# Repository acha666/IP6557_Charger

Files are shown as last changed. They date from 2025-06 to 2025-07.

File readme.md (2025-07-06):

# IP6557 Charger

[Chinese Document / 中文文档](./readme-zh.md) | English Document

*A fast-charging module based on the Injoinic IP6557 buck-boost SoC*  

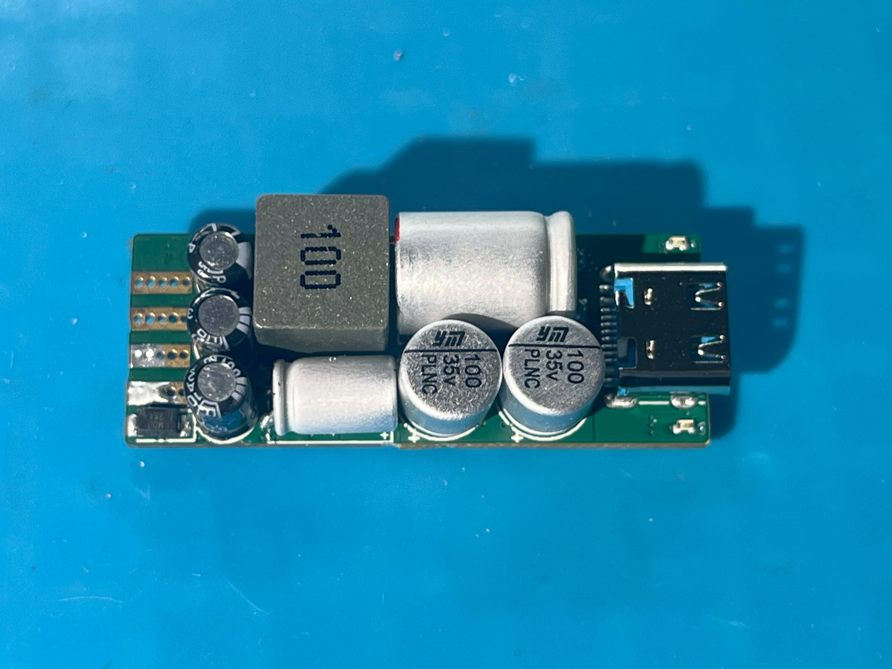
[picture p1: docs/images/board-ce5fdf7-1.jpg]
PCB Photo 1
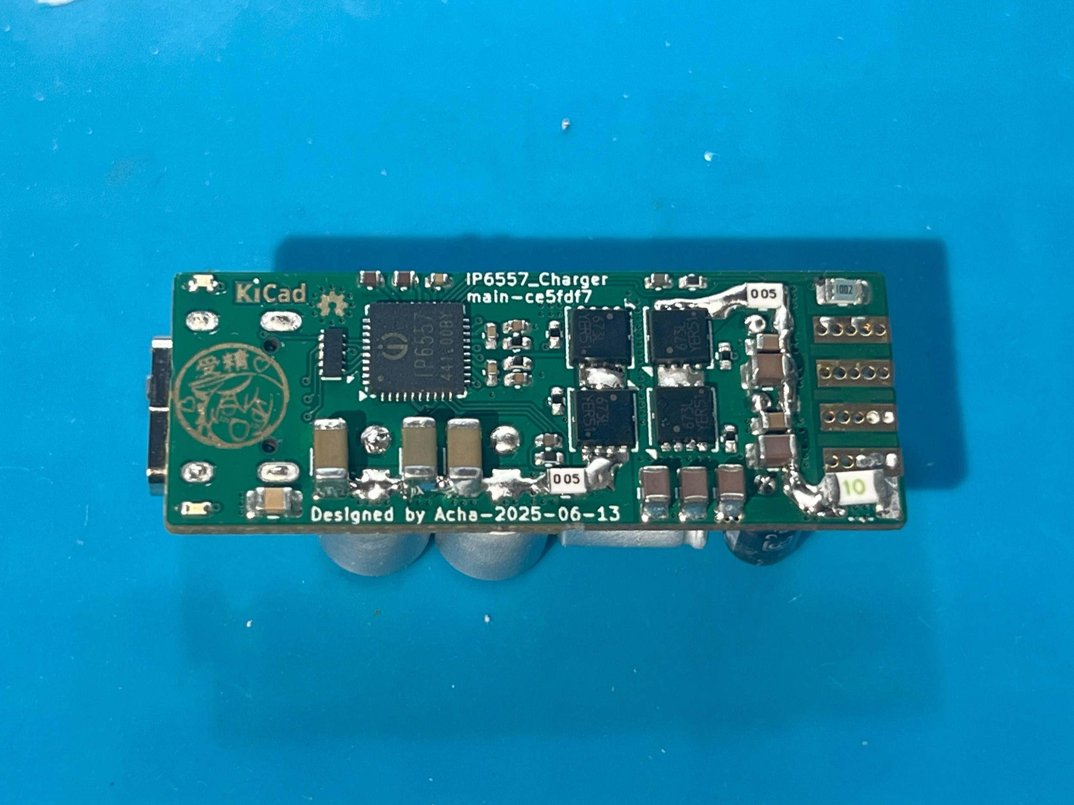
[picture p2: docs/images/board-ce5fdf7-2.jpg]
PCB Photo 2
 

## Project Status

- [x] Schematic design  
- [x] PCB layout  
- [x] PCB fabrication  
- [x] PCB validation  

## Device Overview

- **[IP6557-C]()** – An SoC that integrates a buck-boost controller and USB-C fast-charging protocols  
- **[NTTFS5C673NL](https://www.onsemi.com/download/data-sheet/pdf/nttfs5c673nl-d.pdf) MOSFET** –  
  $`V_{DS}=60\,\text{V},\;R_{DS(\mathrm{on})}=11\,\text{m}\Omega,\;C_{\mathrm{iss}}=880\,\text{pF},\;Q_{g(\mathrm{th})}=1.0\,\text{nC}\;@\,4.5\,\text{V}`$

## Key PCB Parameters

| Parameter | Value |
|:---:|:---:|
| **Dimensions** | 38.50 mm × 14.70 mm |
| **Board shape** | Rounded rectangle, r = 0.50 mm |
| **Finished thickness** | 1.00 mm |
| **Copper layers** | 4 |
| **Min. trace width** | 0.12 mm |
| **Min. trace spacing** | 0.12 mm |
| **Min. plated hole Ø** | 0.20 mm |
| **Min. non-plated hole Ø** | 0.65 mm |
| **Min. via outer Ø** | 0.45 mm |
| **Min. via inner Ø** | 0.20 mm |
| **Min. plated slot width** | 0.60 mm |
| **Min. non-plated slot width** | N/A |

## Project Description

This project was designed with KiCad 9.0.2.

A GitHub Actions CI/CD workflow runs DRC checks and generates manufacturing files (Gerber, etc.) automatically on every commit.

Manufacturing files are available from the [Release page](https://github.com/acha666/IP6557_Charger/releases) or the [Workflow page](https://github.com/acha666/IP6557_Charger/actions/workflows/kicad-ci.yml).

### Notes

*(This document was translated by ChatGPT.)*

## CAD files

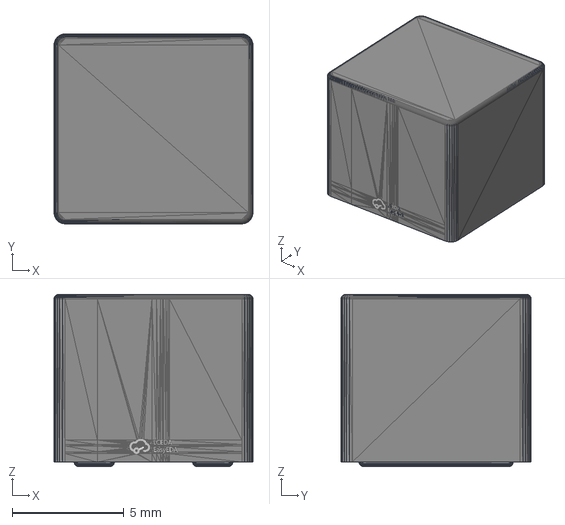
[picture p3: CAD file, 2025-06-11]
IP6557_Charger.3dmodels/IND-SMD_L8.9-W8.5.step
8.90 x 8.51 x 7.70 mm

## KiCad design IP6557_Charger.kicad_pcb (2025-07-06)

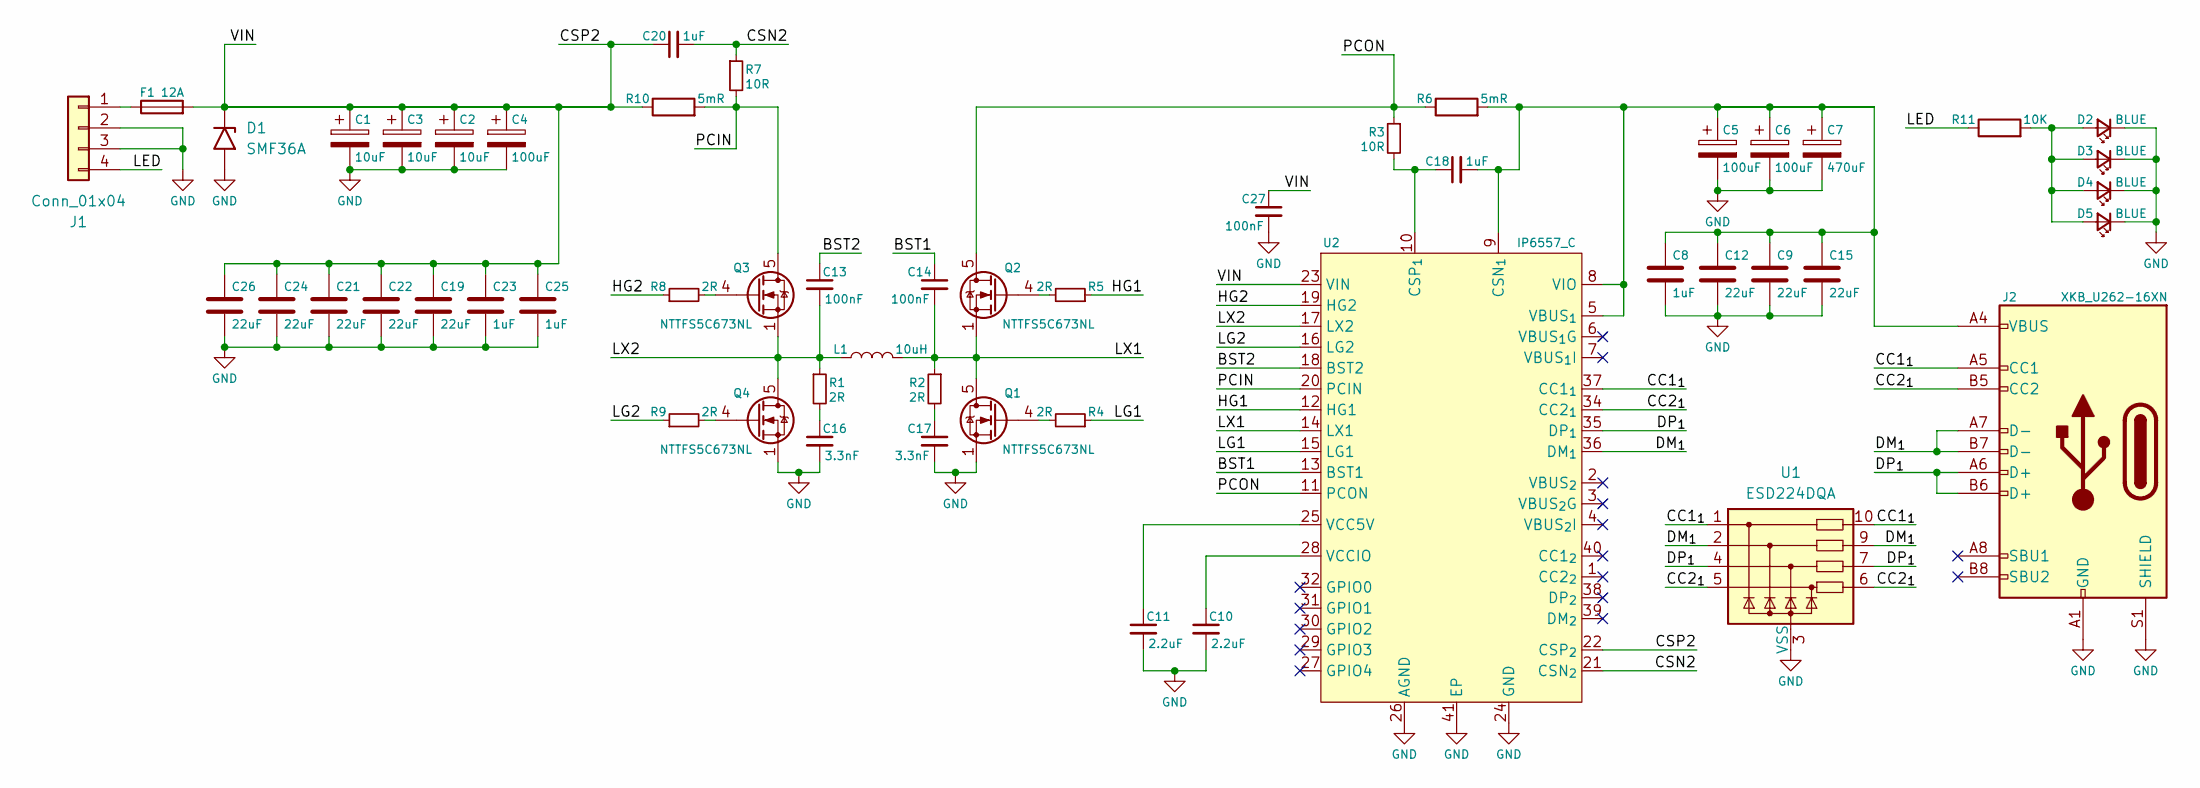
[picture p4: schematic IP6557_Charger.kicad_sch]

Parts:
C1, C2, C3: 10uF; CP_Radial_D4.0mm_P1.50mm
C4: 100uF; CP_Radial_D5.0mm_P2.00mm
C5, C6: 100uF; CP_Radial_D6.3mm_P2.50mm
C7: 470uF; CP_Radial_D8.0mm_P3.50mm
C8: 1uF; C_0805_2012Metric
C9, C12, C15: 22uF; C_1206_3216Metric
C10, C11: 2.2uF; C_0402_1005Metric
C13, C14, C27: 100nF; C_0402_1005Metric
C16, C17: 3.3nF; C_0402_1005Metric
C18, C20: 1uF; C_0402_1005Metric
C19, C21, C22, C24, C26: 22uF; C_0805_2012Metric
C23, C25: 1uF; C_0603_1608Metric
D1: SMF36A; D_SMF
D2, D3, D4, D5: BLUE; LED_0402_1005Metric
F1: 12A; Fuse_1206_3216Metric
J1: Conn_01x04; PinHeader_1x04_P2.54mm_Horizontal
J2: XKB_U262-16XN; USB_C_Receptacle_XKB_U262-16XN-4BVC11
L1: 10uH; L_Changjiang_FEXL0880A
Q1, Q2, Q3, Q4: NTTFS5C673NL; VSON-8_3.3x3.3mm_P0.65mm_NexFET
R1, R2, R4, R5, R8, R9: 2R; R_0402_1005Metric
R3, R7: 10R; R_0402_1005Metric
R6, R10: 5mR; R_0805_2012Metric
R11: 10K; R_0805_2012Metric
U1: ESD224DQA; Diodes_UDFN-10_1.0x2.5mm_P0.5mm
U2: IP6557_C; VQFN-40-1EP_5x5mm_P0.4mm_EP3.6x3.6mm_ThermalVias

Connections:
/BST1: C14.1, U2.13 (BST1)
/BST2: C13.1, U2.18 (BST2)
/CC1_{1}: J2.A5 (CC1), U1.1, U1.10, U2.37 (CC1_{1})
/CC2_{1}: J2.B5 (CC2), U1.5, U1.6, U2.34 (CC2_{1})
/CSN2: C20.2, R7.1, U2.21 (CSN_{2})
/CSP2: C1.1, C2.1, C3.1, C4.1, C19.1, C20.1, C21.1, C22.1, C23.1, C24.1, C25.1, C26.1, C27.1, D1.1 (A1), F1.2, R10.1, U2.22 (CSP_{2}), U2.23 (VIN)
/DM_{1}: J2.A7 (D-), J2.B7 (D-), U1.2, U1.9, U2.36 (DM_{1})
/DP_{1}: J2.A6 (D+), J2.B6 (D+), U1.4, U1.7, U2.35 (DP_{1})
/HG1: R5.1, U2.12 (HG1)
/HG2: R8.1, U2.19 (HG2)
/LED: J1.4, R11.1
/LG1: R4.1, U2.15 (LG1)
/LG2: R9.1, U2.16 (LG2)
/LX1: C14.2, L1.2, Q1.5 (D), Q2.1 (S), Q2.2 (S), Q2.3 (S), R2.1, U2.14 (LX1)
/LX2: C13.2, L1.1, Q3.1 (S), Q3.2 (S), Q3.3 (S), Q4.5 (D), R1.1, U2.17 (LX2)
/PCIN: Q3.5 (D), R7.2, R10.2, U2.20 (PCIN)
/PCON: Q2.5 (D), R3.1, R6.1, U2.11 (PCON)
GND: C1.2, C2.2, C3.2, C4.2, C5.2, C6.2, C7.2, C8.2, C9.2, C10.2, C11.2, C12.2, C15.2, C16.2, C17.2, C19.2, C21.2, C22.2, C23.2, C24.2, C25.2, C26.2, C27.2, D1.2 (A2), D2.1 (K), D3.1 (K), D4.1 (K), D5.1 (K), J1.2, J1.3, J2.A1 (GND), J2.A12 (GND), J2.B1 (GND), J2.B12 (GND), J2.S1 (SHIELD), Q1.1 (S), Q1.2 (S), Q1.3 (S), Q4.1 (S), Q4.2 (S), Q4.3 (S), U1.3 (VSS), U1.8 (VSS), U2.24 (GND), U2.26 (AGND), U2.41 (EP)
unnamed: C16.1, R1.2
unnamed: C17.1, R2.2
unnamed: D2.2 (A), D3.2 (A), D4.2 (A), D5.2 (A), R11.2
unnamed: F1.1, J1.1
unnamed: Q1.4 (G), R4.2
unnamed: Q2.4 (G), R5.2
unnamed: Q3.4 (G), R8.2
unnamed: Q4.4 (G), R9.2
unnamed: C5.1, C6.1, C7.1, C8.1, C9.1, C12.1, C15.1, C18.2, J2.A4 (VBUS), J2.A9 (VBUS), J2.B4 (VBUS), J2.B9 (VBUS), R6.2, U2.5 (VBUS_{1}), U2.8 (VIO), U2.9 (CSN_{1})
unnamed: C18.1, R3.2, U2.10 (CSP_{1})
unnamed: C11.1, U2.25 (VCC5V)
unnamed: C10.1, U2.28 (VCCIO)

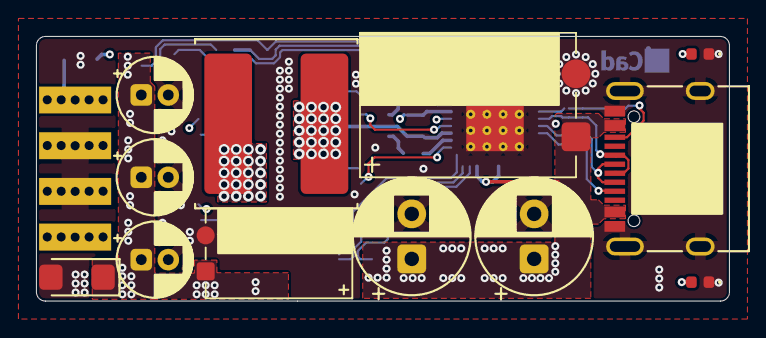
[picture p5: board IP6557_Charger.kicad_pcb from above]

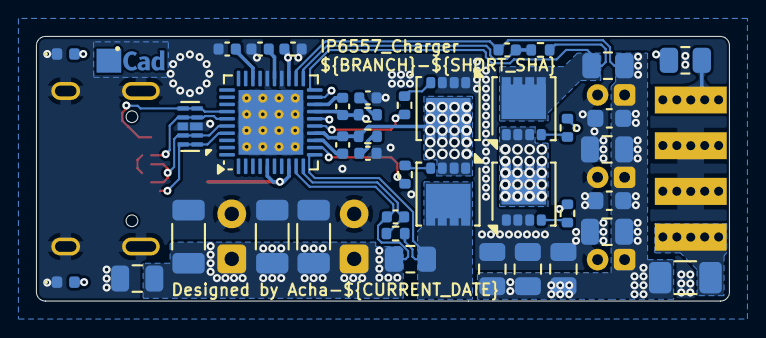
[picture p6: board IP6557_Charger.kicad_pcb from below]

Board: 4 copper layers, 38.5 x 14.7 mm, 53 parts (40 on the bottom side), 30 nets.
